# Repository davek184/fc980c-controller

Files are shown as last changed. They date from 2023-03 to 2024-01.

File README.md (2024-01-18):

# FC980C Controller
Design modifications are based on parent [project](https://github.com/wlhlm/fc980c-controller).  

Similar concept to Hasu 980c controller but it is a nice upgrade in processing limitations vs the Atmega32u4.

Related project [USB-C Daughterboard](https://github.com/davek184/980_Usb_C_Daughterboard)


ImageInstalled

## Warning!!!
There was something wrong with the last 2 batches of these.  2 out of 5 would not properly register the keyboard after flashing.  It was unclear if this a manufacturing mistake from JLCPCB or an issue with the compontents.  Did NOT have time to look into it further, use at your own risk!

## Changes
* Added USB SH Connector
* Added USB Molex EZ-Mate connector
* Added RGB Underglow support (Norbauer Heavy-9 is the only case I know of that could take advantage of this)
* Added MegaMan logo
* Altered Boot0 so it can be shorted with tweezers for those who don't want to solder a switch
* Altered ISP header

## Firmware
* [Precompiled Firmware](/firmware)
* Can also be compiled into QMK or VIAL firmware yourself using files in the [firmware](/firmware/fc980c) directory

Firmware can be flashed with QMK Toolbox.  To get into bootloader mode short the BootO pins (or press and hold the reset switch) **WHILE connecting the USB cable**

## Manufacturing
* Files are set up for JLCPCB.  
* Select Specify a location for Remove Order Number (that will put it in a set location)
* Choose PCB Assembly
  * Assemble top Side
  * Tooling holes Added by customer
  * Confirm parts placement Yes
* Optional Parts
  * J1 The USB Molex EZ-mate connector, is optional and can be deselected to save some money
  * J4 The USB SH connector, is optional and can be deselected to save some money
  * J5 The RGB underglow connector, is optional and can be deselected to save some money

**Note the keyboard connector is not available at this time to be assembled.  It must be soldered by yourself!**

Hirose part number DF14-20P-1.25H(52).  Mouser: https://www.mouser.com/ProductDetail/798-DF1420P125H52

_(This is the same keyboard connector the FC660c uses)_

## Thank you
Thank you to [wlhlm](https://github.com/wlhlm) for all the work that went into this.

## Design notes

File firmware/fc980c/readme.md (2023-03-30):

# Leopold FC980C replacement controller

wlhlm FC980C replacement controller render

* Keyboard Maintainer: [wlhlm](https://github.com/wlhlm)
* Hardware Supported: rev. 1, rev. 2
* [PCB Source](https://github.com/wlhlm/fc980c-controller/)

Make example for this keyboard (after setting up your build environment):

    make leopold/fc980c/wlhlm:default

See the [build environment setup](https://docs.qmk.fm/#/getting_started_build_tools) and the [make instructions](https://docs.qmk.fm/#/getting_started_make_guide) for more information. Brand new to QMK? Start with our [Complete Newbs Guide](https://docs.qmk.fm/#/newbs).

## Flashing the firmware onto the keyboard

To be able to flash the controller, it first has to be brought into bootloader mode. There are three ways this can be accomplished:

- Hold the `BOOT0` button at the back of the controller board (also accessible through the case) pressed while plugging the board into USB.
- Hold the `Escape` key while plugging the board into USB (requires QMK to already be flashed onto the controller).
- Press `Fn+Esc` (requires QMK to already be flashed onto the controller).

After entering bootloader mode, new firmware can be flashed. Make example for flashing this keyboard:

    make leopold/fc980c/wlhlm:default:flash

## Actuation point adjustment

Topre keyboards such as the FC980C are based around capacitive sense and allow adjustment of the actuation point. This feature is not supported by the stock FC980C controller, this replacement controller however unlocks said functionality. Check the `actuation_point_example` keymap for guidance.

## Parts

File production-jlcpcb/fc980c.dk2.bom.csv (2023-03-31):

Designator | Footprint | Quantity | Value | LCSC Part #
C1 | 0402 | 1 | 1uF | C52923
C9, C10 | 0402 | 1 | 20pF | C1554
C5,C6,C11,C12,C13,C14,C150402 | 1 | 100nF | C1525
C2 | 0603 | 1 | 4.7uF | C19666
C3,C4,C8 | 0603 | 1 | 1uF | C15849
C7 | 0603 | 1 | 10uF | C19702
F1 | 1206 | 1 | 500mA | C70076
J1 | Molex_Pico-EZmate_78171-0004_1x04-1MP_P1.20mm_Vertical | 1 | Molex_Pico-EZmate_78171-0004_1x04-1MP_P1.20mm_Vertical | C528030
J2 | JST_PH_S5B-PH-K_1x05_P2.00mm_Horizontal | 1 | USB | C157923
J4 | JST_SH_SM04B-SRSS-TB_1x04-1MP_P1.00mm_Horizontal | 1 | JST_SH_SM04B-SRSS-TB_1x04-1MP_P1.00mm_Horizontal | C160404
J5 | Molex_Pico-EZmate_78171-0003_1x03-1MP_P1.20mm_Vertical | 1 | Molex_Pico-EZmate_78171-0003_1x03-1MP_P1.20mm_Vertical | C528029
R1,R2,R3,R4 | 0402 | 1 | 10k | C25744
U1 | SOT-23 | 1 | XC6206P332MR | C5446
U2 | QFN-48-1EP_7x7mm_P0.5mm_EP5.6x5.6mm | 1 | STM32F401CBUx | C118825
U3 | SOT-23-6 | 1 | USBLC6-2SC6 | C2827654
U4 | SOIC-8_3.9x4.9mm_P1.27mm | 1 | M24C64-RMN6TP | C79988
Y1 | Crystal_SMD_5032-2Pin_5.0x3.2mm | 1 | 8MHz Cl 20pF | C115962

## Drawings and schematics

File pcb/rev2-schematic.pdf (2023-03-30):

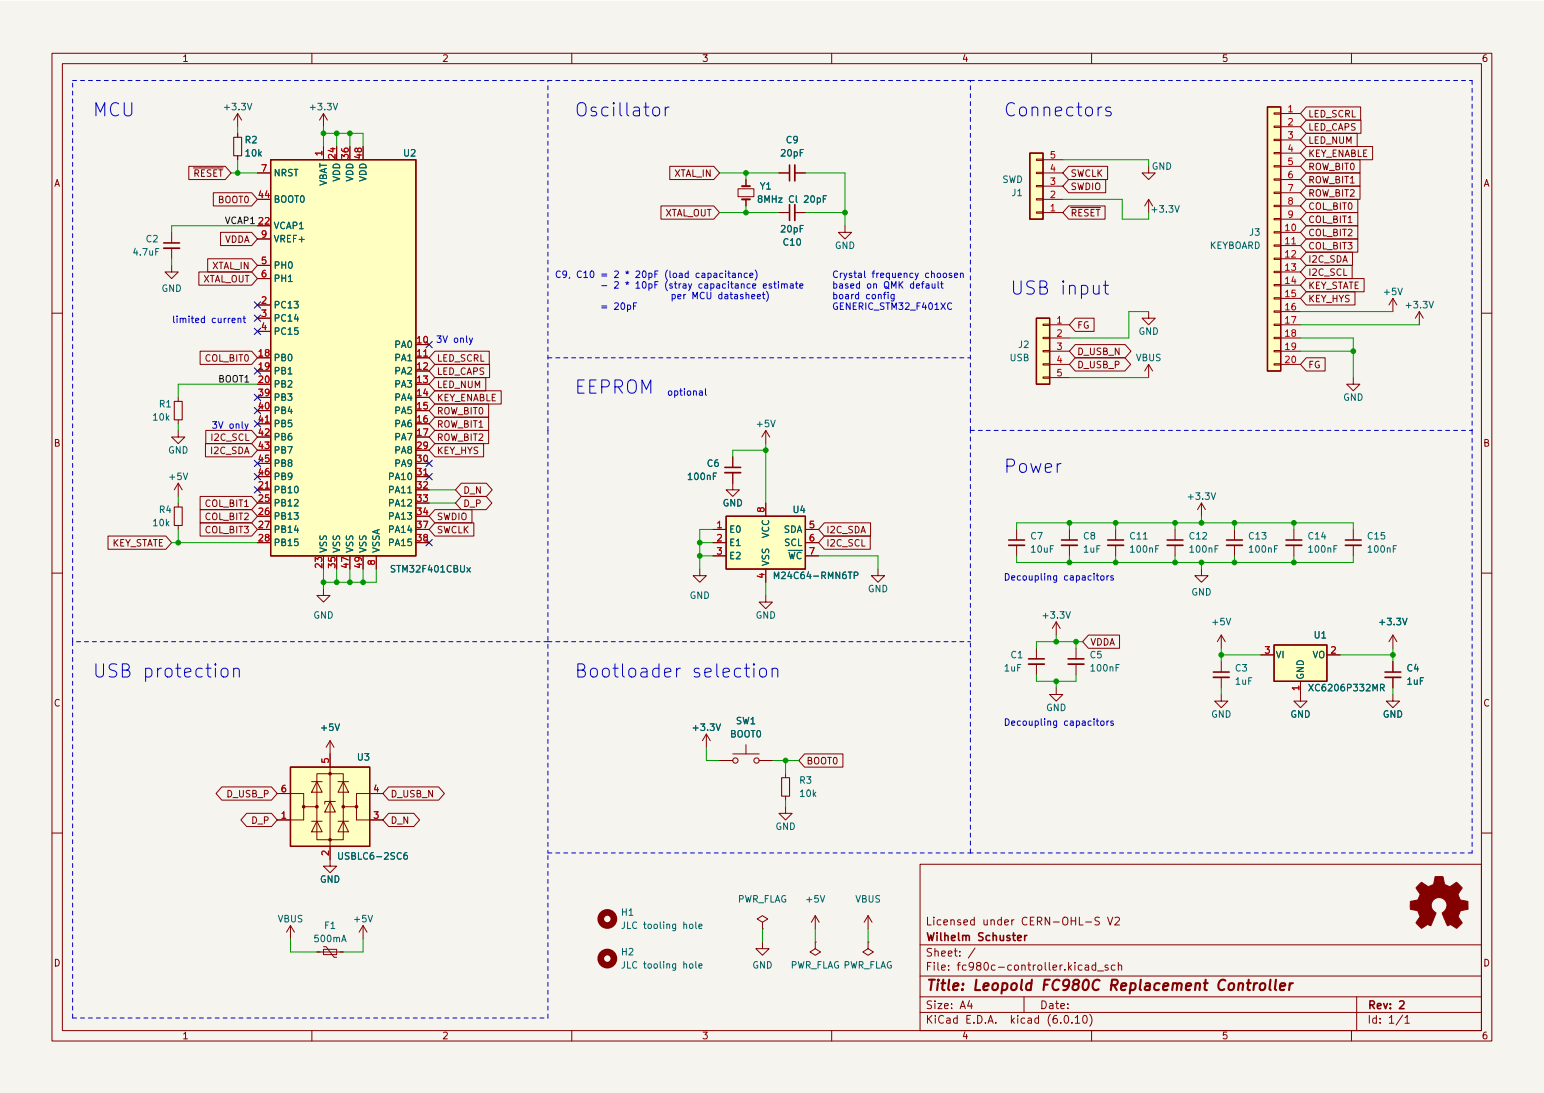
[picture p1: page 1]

based on QMK default board config GENERIC_STM32_F401XC MCU

1 PA0 10 PA1 11 PA2 12 PA3 13 PA4 14 PA5 15 PA6 16 PA7 17 PB0 18 PB1 19 PC13 2 PB2 20 PB10 21 VCAP1 22 VSS 23 VDD 24 PB12 25 PB13 26 PB14 27 PB15 28 PA8 29 PC14 3 PA9 30 PA10 31 PA11 32 PA12 33 PA13 34 VSS 35 VDD 36 PA14 37 PA15 38 PB3 39 PC15 4 PB4 40 PB5 41 PB6 42 PB7 43 BOOT0 44 PB8 45 PB9 46 VSS 47 VDD 48 VSS 49 PH0 5 PH1 6 NRST 7 VSSA

4 SDA 5 SCL 6 ~{WC} 7 VCC

File: fc980c-controller.kicad_sch Sheet: / Wilhelm Schuster Licensed under CERN-OHL-S V2

Id: 1/1 Title: Leopold FC980C Replacement Controller

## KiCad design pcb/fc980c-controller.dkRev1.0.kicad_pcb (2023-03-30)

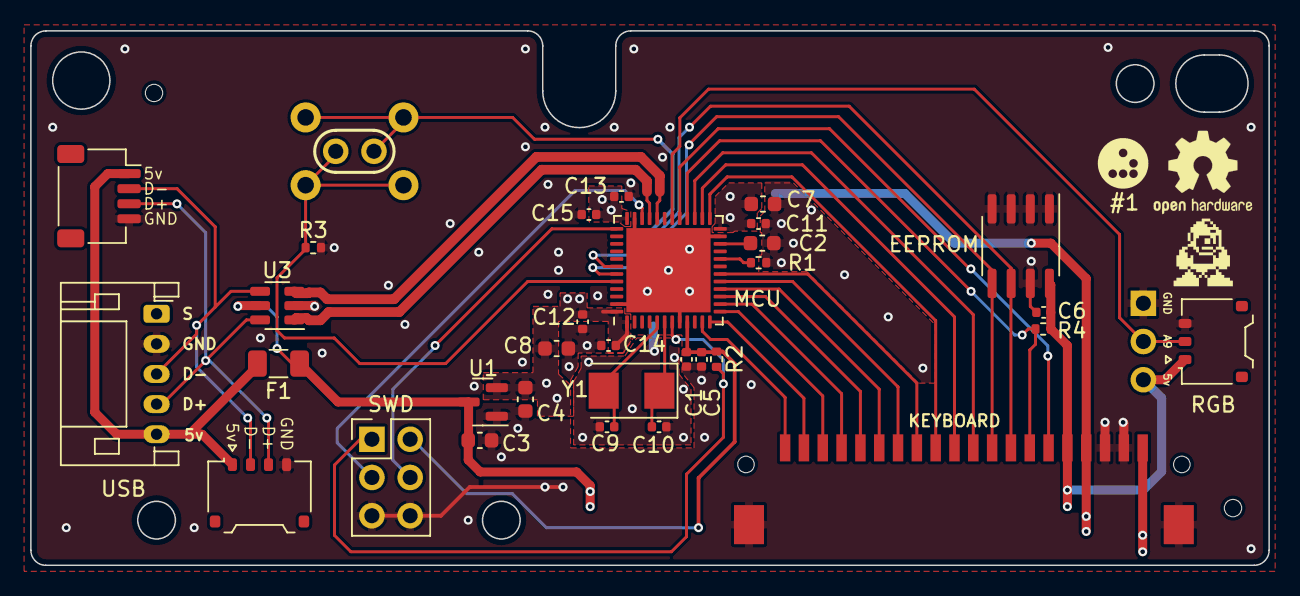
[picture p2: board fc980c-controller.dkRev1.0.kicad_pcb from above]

Board: 2 copper layers, 82.2 x 35.5 mm, 37 parts (1 on the bottom side), 32 nets.

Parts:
C1: 1uF; C_0402_1005Metric
C2: 4.7uF; C_0603_1608Metric
C3, C4, C8: 1uF; C_0603_1608Metric
C5, C6, C11, C12, C13, C14, C15: 100nF; C_0402_1005Metric
C7: 10uF; C_0603_1608Metric
C9, C10: 20pF; C_0402_1005Metric
F1: 500mA; Fuse_1206_3216Metric
H1, H2: JLC tooling hole; JLC_tooling_hole
J1: Molex_Pico-EZmate_78171-0004_1x04-1MP_P1.20mm_Ver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; Molex_Pico-EZmate_78171-0004_1x04-1MP_P1.20mm_Vertical
J2: USB; JST_PH_S5B-PH-K_1x05_P2.00mm_Horizontal
J3: KEYBOARD; HRS_DF14_20P
J4: JST_SH_SM04B-SRSS-TB_1x04-1MP_P1.00mm_Horizontal
J5: Molex_Pico-EZmate_78171-0003_1x03-1MP_P1.20mm_Ver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; Molex_Pico-EZmate_78171-0003_1x03-1MP_P1.20mm_Vertical
J6: PinHeader_1x03_P2.54mm_Vertical
LOGO1: Logo_Open_Hardware_Small; OSHW-Logo2_7.3x6mm_SilkScreen
R1, R2, R3, R4: 10k; R_0402_1005Metric
SW1: PinHeader_1x02_P2.54mm_Vertical
SW1#2: BOOT0; SW_PUSH_6mm
SWD: PinHeader_2x03_P2.54mm_Vertical
U1: XC6206P332MR; SOT-23
U2: STM32F401CBUx; QFN-48-1EP_7x7mm_P0.5mm_EP5.6x5.6mm
U3: USBLC6-2SC6; SOT-23-6
U4: M24C64-RMN6TP; SOIC-8_3.9x4.9mm_P1.27mm
Y1: 8MHz Cl 20pF; Crystal_SMD_5032-2Pin_5.0x3.2mm

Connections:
+5V: C3.1, C6.1, F1.1, J3.16, J5.1, J6.3, R4.1, U1.3 (VI), U3.5 (VBUS), U4.8 (VCC)
/BOOT1: R1.1, U2.20 (PB2)
/VCAP1: C2.1, U2.22 (VCAP1)
BOOT0: R3.1, SW1.1, SW1#2.2, U2.44 (BOOT0)
COL_BIT0: J3.8, U2.18 (PB0)
COL_BIT1: J3.9, U2.25 (PB12)
COL_BIT2: J3.10, U2.26 (PB13)
COL_BIT3: J3.11, U2.27 (PB14)
D_N: U2.32 (PA11), U3.3 (I/O2)
D_P: U2.33 (PA12), U3.1 (I/O1)
D_USB_N: J1.2, J2.3, J4.2, U3.4 (I/O2)
D_USB_P: J1.3, J2.4, J4.3, U3.6 (I/O1)
FG: J2.1, J3.20
GND: C1.2, C2.2, C3.2, C4.2, C5.2, C6.2, C7.2, C8.2, C9.2, C10.2, C11.2, C12.2, C13.2, C14.2, C15.2, J1.4, J2.2, J3.18, J3.19, J3.21, J3.22, J4.4, J5.3, J6.1, R1.2, R3.2, SWD.5, SWD.6, U1.1 (GND), U2.8 (VSSA), U2.23 (VSS), U2.35 (VSS), U2.47 (VSS), U2.49 (VSS), U3.2 (GND), U4.1 (E0), U4.2 (E1), U4.3 (E2), U4.4 (VSS), U4.7 (~WC)
I2C_SCL: J3.13, U2.42 (PB6), U4.6 (SCL)
I2C_SDA: J3.12, U2.43 (PB7), U4.5 (SDA)
KEY_ENABLE: J3.4, U2.14 (PA4)
KEY_HYS: J3.15, U2.29 (PA8)
KEY_STATE: J3.14, R4.2, U2.28 (PB15)
LED_CAPS: J3.2, U2.12 (PA2)
LED_NUM: J3.3, U2.13 (PA3)
LED_SCRL: J3.1, U2.11 (PA1)
ROW_BIT0: J3.5, U2.15 (PA5)
ROW_BIT1: J3.6, U2.16 (PA6)
ROW_BIT2: J3.7, U2.17 (PA7)
SWCLK: SWD.4, U2.37 (PA14)
SWDIO: SWD.3, U2.34 (PA13)
VBUS: F1.2, J1.1, J2.5, J4.1
VDDA: C1.1, C4.1, C5.1, C7.1, C8.1, C11.1, C12.1, C13.1, C14.1, C15.1, J3.17, R2.1, SW1.2, SW1#2.1, SWD.2, U1.2 (VO), U2.1 (VBAT), U2.9 (VREF+), U2.24 (VDD), U2.36 (VDD), U2.48 (VDD)
XTAL_IN: C9.1, U2.5 (PH0), Y1.2
XTAL_OUT: C10.1, U2.6 (PH1), Y1.1
~RESET: R2.2, SWD.1, U2.7 (NRST)

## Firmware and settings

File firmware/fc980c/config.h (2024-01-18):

// Copyright 2022 Wilhelm Schuster
// SPDX-License-Identifier: GPL-2.0-or-later

#pragma once

/* Custom matrix pins and port select array */
#define MATRIX_KEY_ENABLE_PIN A4
#define MATRIX_KEY_STATE_PIN B15
#define MATRIX_KEY_HYS_PIN A8
#define MATRIX_MUX_ROW_PINS {A5, A6, A7}
#define MATRIX_MUX_COL_PINS {B0, B12, B13, B14}

/* While the original BOM uses an M24C64 EEPROM not directly supported by QMK,
 * said EEPROM uses the same parameters as the already supported 24LC64. */
#define EEPROM_I2C_24LC64

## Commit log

2023-03-30 DK Revision
    * Rounded PCB corners,
    * Added USB connectors JST SH
    * Added USB connectors Molex EZ-mate
    * Added RGB underglow
    [BOM-fc980c-controller.csv, RP2040_QFN_PACKAGE.step, fc980c-controller.dkRev1.0.kicad_pcb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]
2023-03-31 Added JST PH Connector to BOM & Position file
    [fc980c.dk2.bom.csv, fc980c.dk2.positions.csv]

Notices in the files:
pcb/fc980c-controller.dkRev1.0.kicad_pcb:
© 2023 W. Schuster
